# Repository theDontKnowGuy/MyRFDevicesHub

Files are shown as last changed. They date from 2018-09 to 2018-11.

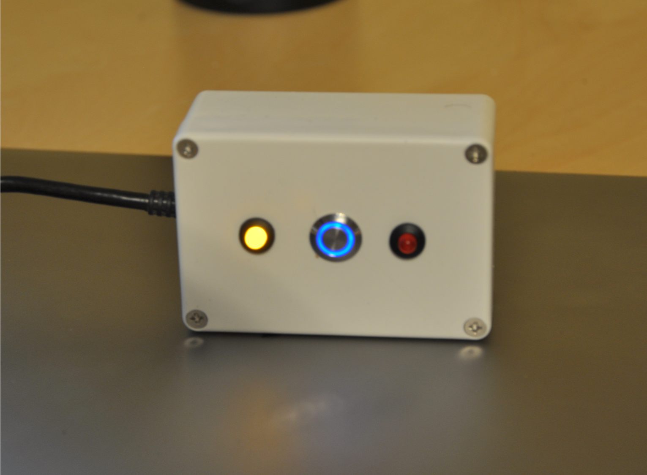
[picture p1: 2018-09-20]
MyRFDevicesHub home.png

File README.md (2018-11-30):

# myRFDevicesHub

Connect all my RF 433 Devices messages and convert them to actions like connect to Smartthings

 * Version 0.8 beta - Migrarion to ESP32. Fixing some shit aroud Wifi client response. Adopting to new ArduinoJson library 6.3.
 * Version 0.7 beta - Maintenance Reboot once a day.Add Web log page.
 * Version 0.6 beta - Reduce network time. Bug fixes.
 * Version 0.5 beta - Support network logging. Adopting to new ArduinoJson library 6.2.3. 
 * Version 0.4 beta - Support set clock and add timestamp to reports and logs
 * Version 0.3 beta - Support dynamic load of new devices
 * Version 0.2 beta
 * credit to the writers of RFControl, ArduinoJson and ESP8266WiFi stacks.
--------------------------------------------------------------------------------------------

So I have so many semy old to dead old 433Mhz RF  devices: from aliexpress 5$ sensors to fancy VISONIC PIR, all sort of remote controls that start stuff, and my kitchen kings meat thermometer which sends signals to its display device (https://www.aliexpress.com/item/Digital-Wireless-LCD-BBQ-Grill-Meat-Oven-Food-Remote-Thermometer-Kitchen-Tool/32758598223.html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) which I love.

I wanted to reutilize the Visonic sensors to my Smartthings hub as Visonic's hub is a stupid box, but their sensors are bloody good.
Reversed engineered the protocol, implemented it in Arduino and was about to close the shop but then decided to add the remote control, then something else than the meat thermometer as I decided that one cannot live his life peacefully without KODI to play a special announcement once the meat gets to the medium-rare point.
Then things started to get out of control. I really wanted to make it generic so little work required, without coding, to add the next stupid device I will find / will must buy on Aliexpress. 

I implemented integration to Smartthings via two ways: One using external, webcore trigger execution URL (via HTTP GET request) and another with posting directly to Smartthings hub on the local network. These are just examples of course which can be expanded.

The hub designed to be aware of error and problems (network) and try to recover from them. A lot to do to bring it to completion.

I am using WEMOS D1R2 but any ESP8266 should work and any Arduino with network access should be OK with some minor code change on the network stack.

![alt text](https://lh3.googleusercontent.com/WBL5oTXWKvsu7guZXq39TpxMiPwH3iJrGACO5EKY5pxy82EF0439uUVmV7iJWcNCj8XLV19bo9rygoG5QiyY6vogaEoI-Da72RzOngfa13abKqSZ0ILgBBKookVFuQRV5vi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)

I am not a programmer. I can write few lines in C but that is about it.  So please forgive any programming flaws and feel free to let me know or to fix them yourself so we will update this project together.

*Installation:* 
1. Download the myRFDevicesHub into your Arduino library (lots of files, one project with tabs so you don't have to scroll like maniacs).
2. Make sure to install RFControl from here https://github.com/pimatic/RFControl
3. As an optional step, place the MyRFDevicesHubLogger.php on a (preferebly local) php web server to save the logs on the network, again so you don't need to go and connect to the hub when you want to know what is going on. Configure the path where logs are saved to on the php file. Configure the path to the php file in the logTarget parameter.
4. As an optional step, place RFDevices.json on the same local network http web server and configure the path to it in the dataUpdateHost, port and URI parameters. This will override the list of devices and protocol, as well as debuglevel, so you don't need to recompile to add a new device or to incease debuglevel.
3. Configure your new life. All configurations are in the upper part of the main tab (myRFDevicesHub) and some are overrided in the json file - so change it there first .
5. Actions: configure the host and URL parameters you want to use. In the out of the box  examples put your secret key, account hash and piston# and it will work.
6. To add new RF devices first try to run them as is. They will be unknown, but if you get a deviceID in the log, the protocol is recognized. ye. add their device ID to the Devices database in the json and you are good to go (for the most part. parameters can be different).
6. If the protocol is not recognized, enlarge the DEBUGLEVEL on the json file and get a printout of the codes received. If you don't get a good split of 0's and 1's in the output, you may want to change the treshhold of the digital reading of the actual radio transmission to a number somewhere between the low numbers and the high number (microseconds of up and down radio signals).

Would love to get your feedback.

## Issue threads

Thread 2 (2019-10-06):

esp8266 crash

glebef, 2019-10-06:
Did you somehow adapt RFControl.h library ?
it is crashing all the time for me (im using pin 25, not 0)

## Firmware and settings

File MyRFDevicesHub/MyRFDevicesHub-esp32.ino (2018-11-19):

/*
 * MyRFDevicesHub  by theDontKnowGuy
 * 
 * Connect all my RF 433 Devices messages and convert them to actions like connect to Smartthings.
 * 
 * Version 1.0 - Completed migration to new network stack which wraps any request generally
 * Version 0.8 beta - Migrarion to ESP32. Fixing some shit aroud Wifi client response. Adopting to new ArduinoJson library 6.3.
 * Version 0.7 beta - Maintenance Reboot once a day.Add Web log page.
 * Version 0.6 beta - Reduce network time. Bug fixes.
 * Version 0.5 beta - Support network logging. Adopting to new ArduinoJson library 6.2.3. 
 * Version 0.4 beta - Support set clock and add timestamp to reports and logs
 * Version 0.3 beta - Support dynamic load of new devices
 * Version 0.2 beta
 * credit to the writers of RFControl, ArduinoJson and ESP8266WiFi stacks.
 */

int DEBUGLEVEL = 1;   // set between 0 and 5. This value will be overridden by dynamic network configuration json
int maintenanceRebootHour = 4;  // the hub will reboot once a day at aproximitly this UTC hour (default 4 am), provided it was running ~24 hours

//////////////////////////Define Here New Device///////////////////////////////////////////////////////
typedef struct { String Name; String location; String ID; String type; int messasgeLength; int protocol;} RFDevices;

#define MaxNoOfDevices 100    // maximum devices acceptable to load dynamicly from remote configuration (via http call). change if not enough.

int NoOfDevices=5;        // how many devices are defined in the list below (hardcoded).
RFDevices Devices[MaxNoOfDevices] = {{"Salon Curtain Motion Detector", "SalonDoor",    "0xcfee1","PIR",        74,1},
                                     {"Switch on garden lights",       "GardenLights", "0x8cba3","RemoteBtn",  50,2},
                                     {"Switch off garden lights",      "SomeWhere",    "0x7345c","RemoteBtn",  50,2},                               
                                     {"Another Motion Detector",       "Somewhere",    "0xc2107","PIR2",       50,3},
                                     {"Kitchen termometer",            "Kitchen",      "0x880",  "Termometer", 66,4}};
                               
//////////////////////////Define Here New Protocols Treshold and MessageLength///////////////////////////////////////////////////////
typedef struct {int LongShortTH; int messageLength; int deviceNameLength;}  RFProtocols;
#define NoOfSupportedProtocols 4
RFProtocols SupportedProtocols[] = {{550,   50,   20},
                                    {550,   74,   20},
                                    {1500,  66,   12},
                                    {550,   00,   20}};//// last one if for unknowns. add new ones above this line.

//////////////////////////Define Here Local Network and Data Update Server if any (optional) ///////////////////////////////////////////////////////

const char* ssid =    "xxx";
const char* password ="dddd";
const int   httpsPort=443;

char* dataUpdateHost = "192.168.1.200"; 
int dataUpdatePort = 80;
String dataUpdateURI = "/MyRFDevicesHub/MyRFDevicesHub.json";   /// see example json file in github. leave value empty is no local server (use hardcoded values above)
String logTarget =     "/MyRFDevicesHub/MyRFDevicesHubLogger.php"; /// leave empty if no local logging server (will only Serial.print logs)

typedef struct {int resultCode; String header; String body; int headerLength; int bodyLength;} NetworkResponse;
typedef struct {int resultCode; String line;} NetworkExecResponse;

//////////////////////////Define Here possible actions (for different devices) ///////////////////////////////////////////////////////
typedef struct {String actionType; char* actionParam1; String actionParam2; String actionParam3; String successValidator;}  Actions;
#define NoOfDevicesMessageLengths 3
Actions myActions[] = {{"httpPostLocal", "192.168.1.210", "39500","status","HTTP/1.1 202 ACCEPTED"},
                       {"httpGetSTCloud","graph-na02-useast1.api.smartthings.com", "443", "/api/token/xxxxxxsecretxxxxx/smartapps/installations/<yourendpoint>/execute/:<webcore id>:","{\"result\":\"OK\""},
                       {"IFTTT",          "host3",           "ExternalDeviceName","temperature","successValidator"},
                       {"whateverelse",   "host4",           "ExternalDeviceName","status","successValidator"}};
 
//////////////////////////Define Here associations between devices to the required action. index refers ///////////////////////////////////////////////////////
#define NoOfDeviceActions 4
typedef struct {String deviceType; int actionIdx;}  DevicesAction;
DevicesAction myDevicesActions[] = {{"PIR",       1}, /// <----- this code refers to myActions above
                                    {"RemoteBtn", 1},
                                    {"Termometer",1},
                                    {"PIR2",      0}};

//////////////////////////Define a device runtime status and available capabilties ///////////////////////////////////////////////////////
typedef struct {int idx; String ID; String deviceStatus; int messageLength; int protocolIdx;
                bool IsMove = false; bool IsTamper = false; bool IsLowBat = false; bool IsPing = false; 
                bool IsUnkown = false; int temperature = 999;} RFDevice;

int DeviceMessageLength = -1;

//////////////////////////in high debug level get heapsize and more///////////////////////
#include <WiFiClient.h>
#include <WiFiClientSecure.h>
#include <ArduinoJson.h>
#include <RFControl.h>
#include <TimeLib.h>

#define RFmessageLength 80
int timingsBins[RFmessageLength], BinsStream[RFmessageLength];
int MaxValidLengthTH = 2000, LivePulseLedStatus = 0; 
unsigned long totalLifes, LiveSignalPreviousMillis = millis(); 
bool isDeviceExist, isSetup = true;
String logBuffer = "";

//////////////////////////Define here control lights //////////////////////
#define red 5
#define yellow 19
#define blue 21

void setup() {

    pinMode(red, OUTPUT);pinMode(yellow, OUTPUT);pinMode(blue, OUTPUT);               
    digitalWrite(red, HIGH);delay(200); digitalWrite(red, LOW);digitalWrite(yellow, HIGH);delay(200); digitalWrite(yellow, LOW);delay(200);digitalWrite(blue, HIGH);delay(200); digitalWrite(blue, LOW);

    Serial.begin(115200); logThis("Starting MyRFDevicesHub...",3); 
      
    if (initiateNetwork()>0) {networkReset();}

 //   logThis(5, "Avail heap mem: " + String(system_get_free_heap_size()));

    loadRemoteConfiguration();

    RFControl::startReceiving(25);    //ץ wemos D1R2 GPIO14-->D5. default casued boot problems. //ESP32  25. Some lower ones caused problems.
    
    logThis("Initialization Completed."); 
    digitalWrite(blue, HIGH); // system live indicator
}
 
void loop() {
  
  blinkLiveLed();
  if(RFControl::hasData()) {

                int myInxDevice = -1;
                RFDevice myDevice;
                getDeviceDetails(&myDevice);
                getDeviceStatus(&myDevice);
           
                if (isDeviceExist) {
                    AnalyzeDeviceStatus(&myDevice);
                    int r = eventAction(myDevice);}
                else // device not recognized
                    ReportUnkownDevice(myDevice);
                }
  RFControl::continueReceiving();

}

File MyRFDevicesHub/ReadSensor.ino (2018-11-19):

int* GetRawData(){
    
    unsigned int *timings;
    unsigned int timings_size;
    unsigned int pulse_length_divider = RFControl::getPulseLengthDivider();   
    RFControl::getRaw(&timings, &timings_size);
    DeviceMessageLength = timings_size;   

    for(int i=0; i < timings_size; i++) {   
        unsigned long timing = timings[i] * pulse_length_divider;
        timingsBins[i] = timing;
      }
    return timingsBins;
}

void Length2bin(){

   int* timingsBins = GetRawData(); 
   int LongShortTH = IdentityDeviceByMessageLength();  
      
   switch (DeviceMessageLength) {
      
        case 50:        // usual remote control. regular interpetation
                for (int i=0 ; i < DeviceMessageLength/2 ; i++)  {      
                if (timingsBins[i*2] < LongShortTH) BinsStream[i]=0;
                else if (timingsBins[i*2] < MaxValidLengthTH) BinsStream[i]=1;
                else BinsStream[i]= -1;
                }
        break;
        case 74:        // visonic. 1 and 0 replaced.
                for (int i=0 ; i < DeviceMessageLength/2; i++)  {      
                if (timingsBins[i*2] < LongShortTH) BinsStream[i]=1;
                else if (timingsBins[i*2] < MaxValidLengthTH) BinsStream[i]=0;
                else BinsStream[i]= -1;
                }
        break;
        case 66:        //kitchen termometer - start one byte later
                for (int i=0 ; i < DeviceMessageLength/2 ; i++)  {      
                if (timingsBins[i*2+1] < LongShortTH) BinsStream[i]=0;
                else if (timingsBins[i*2+1] < MaxValidLengthTH) BinsStream[i]=1;
                else BinsStream[i]= -1; 
                }           
        break;

        }  // switch case

    if (DEBUGLEVEL > 3){
      for(int i=0;i<DeviceMessageLength;i++)  {logThis(String(timingsBins[i]),0);logThis(",",0);}logThis("");
      for(int i=0;i<DeviceMessageLength/2;i++){logThis(String(BinsStream[i]),0); logThis(", ,",0);}logThis("");
    }
}
 
int IdentityDeviceByMessageLength(){
    int LongShortTH = 0;  
    for (int i=0 ; i < NoOfDevicesMessageLengths; i++){
        if(DeviceMessageLength == SupportedProtocols[i].messageLength) LongShortTH = SupportedProtocols[i].LongShortTH;                 
     } 
    if (LongShortTH == 0) {
                             LongShortTH = 550; //default value  for unknown
                             logThis(1,"**Device message length not recognized. using Treshhold default level**",2);
    }
    return LongShortTH;
}
      

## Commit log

2018-07-10 0.23 Fritz diagram
    [myRFDevicesHub.fzz]
2018-07-10 Revert "0.23 Fritz diagram"
    This reverts commit c58adfaaad37e504385d97a426e7a7343846a7fa.
    [myRFDevicesHub.fzz]
2018-07-11 0.31 beta
    [myRFDevicesHub.fzz]
2018-07-22 0.4 beta - support dynamic load of new devices
2018-07-22 0.4 beta - support dynamic load of new devices
2018-07-27 Revert "0.31 beta"
    This reverts commit 0934394c946a27e5077411dc84f40afc0adf32c5.
    [myRFDevicesHub.fzz]
2018-07-29 0.7 beta - Web Logger Viewer Php example
    [myRFDevicesHub.fzz]
2018-09-20 Version 0.8 beta - Migrarion to ESP32
    Version 0.8 beta - Migrarion to ESP32. Fixing some shit aroud Wifi client response. Adopting to new ArduinoJson library 6.3.
    [EventAction.ino, MyRFDevicesHub.ino, httpcalls.ino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]
2018-09-20 Device home
